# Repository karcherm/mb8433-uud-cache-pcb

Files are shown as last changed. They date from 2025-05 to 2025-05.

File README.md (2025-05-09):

1MB cache module for the Biostar MB-8433-UUD mainboard
======================================================

This adapter PCB enables you to install cache using SOJ32 chips, which are still in production. Furthermore,
with a modification of the mainboard, you can install up to 1MB of cache. To support 1MB of cache, you need
to grab A19 from the CPU and route it to the square header pin at the corner of this PCB.

Assembly hints
=========
For U1 to U8 (data RAM): Use 128k x 8 SRAM chips - the layout is not meant for 32k x 8 chips:
Neither does the address line ordering omit the "correct" lines if you install 32k x 8 chips,
nor is there sufficient bypassing at the Vcc pin for SOJ28 chips.

U9 can be a 128k x 8 or 64k x 8 SRAM chip. In case you just need 512K of cache, you can downgrade
U9 to 32k x 8. Sufficient bypassing for a 32k x 8 chip is present at this location. You can *not* downgrade
the data RAM to 64k x 8, though, as the address routing in version 1.1 is not adapted to this scenario.

Make sure to use sufficiently thin pins for plugging into the cache sockets.

Pay attention to the orientation of the memory chips: Pin 1 is always to the edge of the PCB, i.e.
U1-U4 are oriented the other way as U5-U9.

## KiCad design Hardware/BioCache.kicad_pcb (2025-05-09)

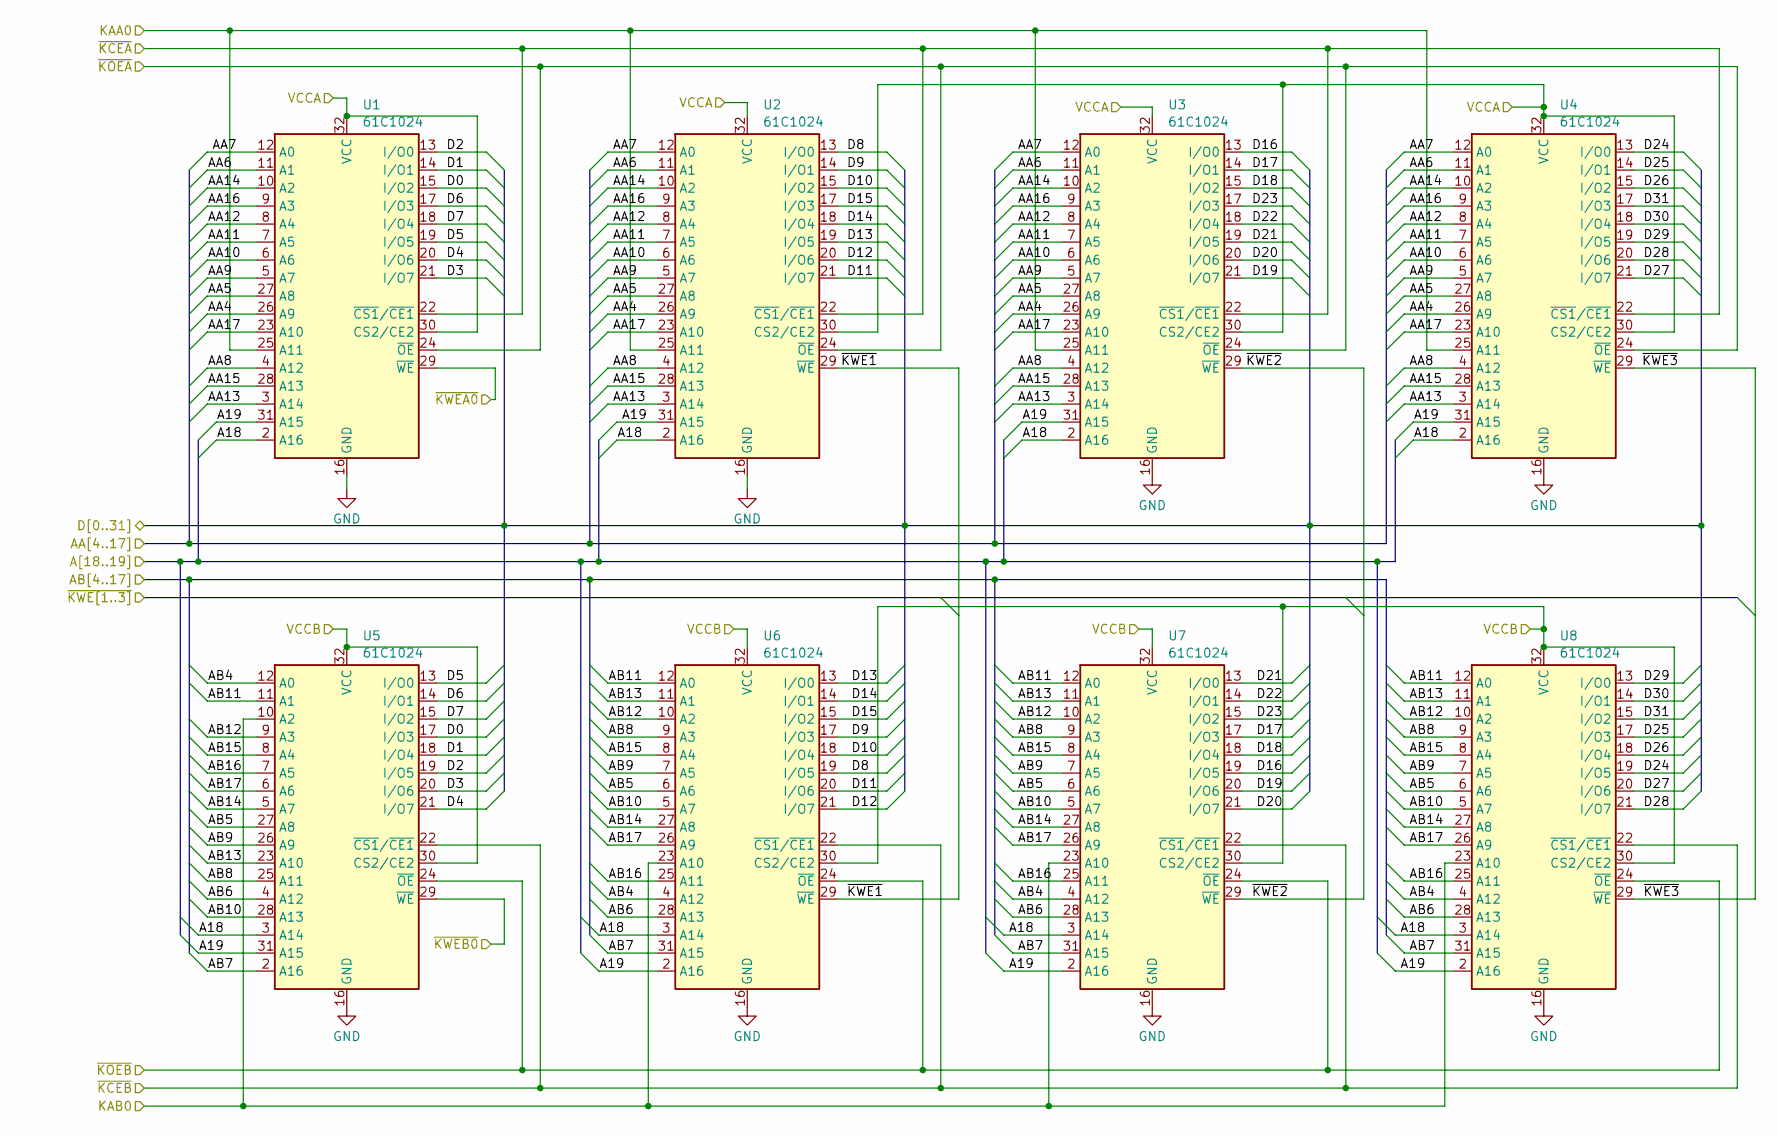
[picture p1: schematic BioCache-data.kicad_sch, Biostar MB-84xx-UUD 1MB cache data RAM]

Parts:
U1, U2, U3, U4, U5, U6, U7, U8: 61C1024; SOJ-32_7.62x20.955mm_P1.27mm

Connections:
/Data RAM/A18: U1.2 (A16), U2.2 (A16), U3.2 (A16), U4.2 (A16), U5.3 (A14), U6.3 (A14), U7.3 (A14), U8.3 (A14); also elsewhere on the board
/Data RAM/A19: U1.31 (A15), U2.31 (A15), U3.31 (A15), U4.31 (A15), U5.31 (A15), U6.2 (A16), U7.2 (A16), U8.2 (A16); also elsewhere on the board
/Data RAM/AA4: U1.26 (A9), U2.26 (A9), U3.26 (A9), U4.26 (A9); also elsewhere on the board
/Data RAM/AA5: U1.27 (A8), U2.27 (A8), U3.27 (A8), U4.27 (A8); also elsewhere on the board
/Data RAM/AA6: U1.11 (A1), U2.11 (A1), U3.11 (A1), U4.11 (A1); also elsewhere on the board
/Data RAM/AA7: U1.12 (A0), U2.12 (A0), U3.12 (A0), U4.12 (A0); also elsewhere on the board
/Data RAM/AA8: U1.4 (A12), U2.4 (A12), U3.4 (A12), U4.4 (A12); also elsewhere on the board
/Data RAM/AA9: U1.5 (A7), U2.5 (A7), U3.5 (A7), U4.5 (A7); also elsewhere on the board
/Data RAM/AA10: U1.6 (A6), U2.6 (A6), U3.6 (A6), U4.6 (A6); also elsewhere on the board
/Data RAM/AA11: U1.7 (A5), U2.7 (A5), U3.7 (A5), U4.7 (A5); also elsewhere on the board
/Data RAM/AA12: U1.8 (A4), U2.8 (A4), U3.8 (A4), U4.8 (A4); also elsewhere on the board
/Data RAM/AA13: U1.3 (A14), U2.3 (A14), U3.3 (A14), U4.3 (A14); also elsewhere on the board
/Data RAM/AA14: U1.10 (A2), U2.10 (A2), U3.10 (A2), U4.10 (A2); also elsewhere on the board
/Data RAM/AA15: U1.28 (A13), U2.28 (A13), U3.28 (A13), U4.28 (A13); also elsewhere on the board
/Data RAM/AA16: U1.9 (A3), U2.9 (A3), U3.9 (A3), U4.9 (A3); also elsewhere on the board
/Data RAM/AA17: U1.23 (A10), U2.23 (A10), U3.23 (A10), U4.23 (A10); also elsewhere on the board
/Data RAM/AB4: U5.12 (A0), U6.4 (A12), U7.4 (A12), U8.4 (A12); also elsewhere on the board
/Data RAM/AB5: U5.27 (A8), U6.6 (A6), U7.6 (A6), U8.6 (A6); also elsewhere on the board
/Data RAM/AB6: U5.4 (A12), U6.28 (A13), U7.28 (A13), U8.28 (A13); also elsewhere on the board
/Data RAM/AB7: U5.2 (A16), U6.31 (A15), U7.31 (A15), U8.31 (A15); also elsewhere on the board
/Data RAM/AB8: U5.25 (A11), U6.9 (A3), U7.9 (A3), U8.9 (A3); also elsewhere on the board
/Data RAM/AB9: U5.26 (A9), U6.7 (A5), U7.7 (A5), U8.7 (A5); also elsewhere on the board
/Data RAM/AB10: U5.28 (A13), U6.5 (A7), U7.5 (A7), U8.5 (A7); also elsewhere on the board
/Data RAM/AB11: U5.11 (A1), U6.12 (A0), U7.12 (A0), U8.12 (A0); also elsewhere on the board
/Data RAM/AB12: U5.9 (A3), U6.10 (A2), U7.10 (A2), U8.10 (A2); also elsewhere on the board
/Data RAM/AB13: U5.23 (A10), U6.11 (A1), U7.11 (A1), U8.11 (A1); also elsewhere on the board
/Data RAM/AB14: U5.5 (A7), U6.27 (A8), U7.27 (A8), U8.27 (A8); also elsewhere on the board
/Data RAM/AB15: U5.8 (A4), U6.8 (A4), U7.8 (A4), U8.8 (A4); also elsewhere on the board
/Data RAM/AB16: U5.7 (A5), U6.25 (A11), U7.25 (A11), U8.25 (A11); also elsewhere on the board
/Data RAM/AB17: U5.6 (A6), U6.26 (A9), U7.26 (A9), U8.26 (A9); also elsewhere on the board
/Data RAM/D0: U1.15 (I/O2), U5.17 (I/O3); also elsewhere on the board
/Data RAM/D1: U1.14 (I/O1), U5.18 (I/O4); also elsewhere on the board
/Data RAM/D2: U1.13 (I/O0), U5.19 (I/O5); also elsewhere on the board
/Data RAM/D3: U1.21 (I/O7), U5.20 (I/O6); also elsewhere on the board
/Data RAM/D4: U1.20 (I/O6), U5.21 (I/O7); also elsewhere on the board
/Data RAM/D5: U1.19 (I/O5), U5.13 (I/O0); also elsewhere on the board
/Data RAM/D6: U1.17 (I/O3), U5.14 (I/O1); also elsewhere on the board
/Data RAM/D7: U1.18 (I/O4), U5.15 (I/O2); also elsewhere on the board
/Data RAM/D8: U2.13 (I/O0), U6.19 (I/O5); also elsewhere on the board
/Data RAM/D9: U2.14 (I/O1), U6.17 (I/O3); also elsewhere on the board
/Data RAM/D10: U2.15 (I/O2), U6.18 (I/O4); also elsewhere on the board
/Data RAM/D11: U2.21 (I/O7), U6.20 (I/O6); also elsewhere on the board
/Data RAM/D12: U2.20 (I/O6), U6.21 (I/O7); also elsewhere on the board
/Data RAM/D13: U2.19 (I/O5), U6.13 (I/O0); also elsewhere on the board
/Data RAM/D14: U2.18 (I/O4), U6.14 (I/O1); also elsewhere on the board
/Data RAM/D15: U2.17 (I/O3), U6.15 (I/O2); also elsewhere on the board
/Data RAM/D16: U3.13 (I/O0), U7.19 (I/O5); also elsewhere on the board
/Data RAM/D17: U3.14 (I/O1), U7.17 (I/O3); also elsewhere on the board
/Data RAM/D18: U3.15 (I/O2), U7.18 (I/O4); also elsewhere on the board
/Data RAM/D19: U3.21 (I/O7), U7.20 (I/O6); also elsewhere on the board
/Data RAM/D20: U3.20 (I/O6), U7.21 (I/O7); also elsewhere on the board
/Data RAM/D21: U3.19 (I/O5), U7.13 (I/O0); also elsewhere on the board
/Data RAM/D22: U3.18 (I/O4), U7.14 (I/O1); also elsewhere on the board
/Data RAM/D23: U3.17 (I/O3), U7.15 (I/O2); also elsewhere on the board
/Data RAM/D24: U4.13 (I/O0), U8.19 (I/O5); also elsewhere on the board
/Data RAM/D25: U4.14 (I/O1), U8.17 (I/O3); also elsewhere on the board
/Data RAM/D26: U4.15 (I/O2), U8.18 (I/O4); also elsewhere on the board
/Data RAM/D27: U4.21 (I/O7), U8.20 (I/O6); also elsewhere on the board
/Data RAM/D28: U4.20 (I/O6), U8.21 (I/O7); also elsewhere on the board
/Data RAM/D29: U4.19 (I/O5), U8.13 (I/O0); also elsewhere on the board
/Data RAM/D30: U4.18 (I/O4), U8.14 (I/O1); also elsewhere on the board
/Data RAM/D31: U4.17 (I/O3), U8.15 (I/O2); also elsewhere on the board
/Data RAM/KAA0: U1.25 (A11), U2.25 (A11), U3.25 (A11), U4.25 (A11); also elsewhere on the board
/Data RAM/KAB0: U5.10 (A2), U6.23 (A10), U7.23 (A10), U8.23 (A10); also elsewhere on the board
/Data RAM/~KCEA: U1.22 (~CS1/~CE1), U2.22 (~CS1/~CE1), U3.22 (~CS1/~CE1), U4.22 (~CS1/~CE1); also elsewhere on the board
/Data RAM/~KCEB: U5.22 (~CS1/~CE1), U6.22 (~CS1/~CE1), U7.22 (~CS1/~CE1), U8.22 (~CS1/~CE1); also elsewhere on the board
/Data RAM/~KOEA: U1.24 (~OE), U2.24 (~OE), U3.24 (~OE), U4.24 (~OE); also elsewhere on the board
/Data RAM/~KOEB: U5.24 (~OE), U6.24 (~OE), U7.24 (~OE), U8.24 (~OE); also elsewhere on the board
/Data RAM/~KWE1: U2.29 (~WE), U6.29 (~WE); also elsewhere on the board
/Data RAM/~KWE2: U3.29 (~WE), U7.29 (~WE); also elsewhere on the board
/Data RAM/~KWE3: U4.29 (~WE), U8.29 (~WE); also elsewhere on the board
/Data RAM/~KWEA0: U1.29 (~WE); also elsewhere on the board
/Data RAM/~KWEB0: U5.29 (~WE); also elsewhere on the board
/Tag RAM and Connectors/VCCA: U1.30 (CS2/CE2), U1.32 (VCC), U2.30 (CS2/CE2), U2.32 (VCC), U3.30 (CS2/CE2), U3.32 (VCC), U4.30 (CS2/CE2), U4.32 (VCC); also elsewhere on the board
/Tag RAM and Connectors/VCCB: U5.30 (CS2/CE2), U5.32 (VCC), U6.30 (CS2/CE2), U6.32 (VCC), U7.30 (CS2/CE2), U7.32 (VCC), U8.30 (CS2/CE2), U8.32 (VCC); also elsewhere on the board
GND: U1.16 (GND), U2.16 (GND), U3.16 (GND), U4.16 (GND), U5.16 (GND), U6.16 (GND), U7.16 (GND), U8.16 (GND); also elsewhere on the board

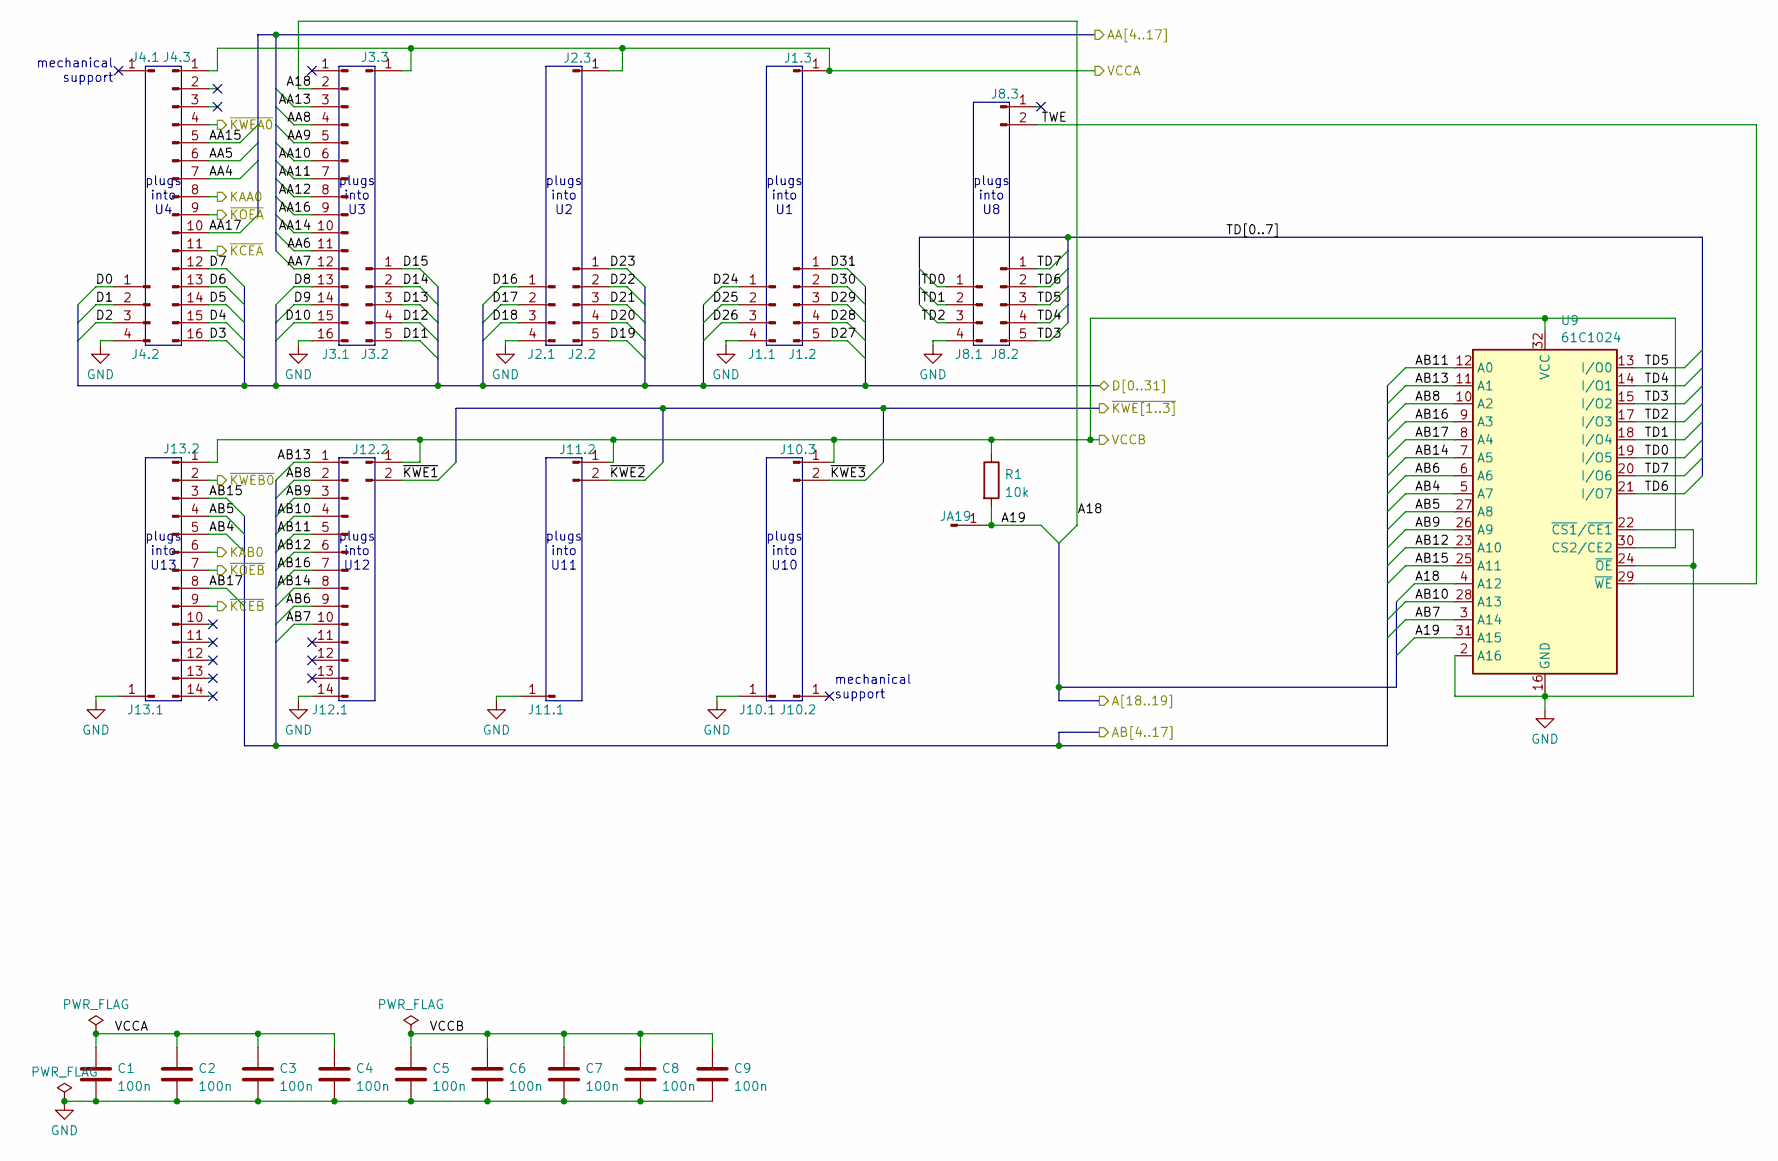
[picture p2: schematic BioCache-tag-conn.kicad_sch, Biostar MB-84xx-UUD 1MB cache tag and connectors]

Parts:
C1, C2, C3, C4, C5, C6, C7, C8, C9: 100n; C_0805_2012Metric_Pad1.18x1.45mm_HandSolder
J1.1, J2.1, J4.2, J8.1: Conn_01x04_Male; PinHeader_1x04_P2.54mm_Vertical_NoSquare1
J1.2, J2.2, J3.2, J8.2: Conn_01x05_Male; PinHeader_1x05_P2.54mm_Vertical_NoSquare1
J1.3, J2.3, J3.3, J4.1, J10.1, J10.2, J11.1, J13.1: Conn_01x01_Male; PinHeader_1x01_P2.54mm_Vertical_NoSquare1
J3.1, J4.3: Conn_01x16_Male; PinHeader_1x16_P2.54mm_Vertical_NoSquare1
J8.3, J10.3, J11.2, J12.2: Conn_01x02_Male; PinHeader_1x02_P2.54mm_Vertical_NoSquare1
J12.1, J13.2: Conn_01x14_Male; PinHeader_1x14_P2.54mm_Vertical_NoSquare1
JA19: Conn_01x01_Male; PinHeader_1x01_P2.54mm_Horizontal
R1: 10k; R_0805_2012Metric_Pad1.20x1.40mm_HandSolder
U9: 61C1024; SOJ-32_7.62x20.955mm_P1.27mm

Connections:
/Data RAM/A18: J3.1.2, U9.4 (A12); also elsewhere on the board
/Data RAM/A19: JA19.1, R1.2, U9.31 (A15); also elsewhere on the board
/Data RAM/AA4: J4.3.7; also elsewhere on the board
/Data RAM/AA5: J4.3.6; also elsewhere on the board
/Data RAM/AA6: J3.1.11; also elsewhere on the board
/Data RAM/AA7: J3.1.12; also elsewhere on the board
/Data RAM/AA8: J3.1.4; also elsewhere on the board
/Data RAM/AA9: J3.1.5; also elsewhere on the board
/Data RAM/AA10: J3.1.6; also elsewhere on the board
/Data RAM/AA11: J3.1.7; also elsewhere on the board
/Data RAM/AA12: J3.1.8; also elsewhere on the board
/Data RAM/AA13: J3.1.3; also elsewhere on the board
/Data RAM/AA14: J3.1.10; also elsewhere on the board
/Data RAM/AA15: J4.3.5; also elsewhere on the board
/Data RAM/AA16: J3.1.9; also elsewhere on the board
/Data RAM/AA17: J4.3.10; also elsewhere on the board
/Data RAM/AB4: J13.2.5, U9.5 (A7); also elsewhere on the board
/Data RAM/AB5: J13.2.4, U9.27 (A8); also elsewhere on the board
/Data RAM/AB6: J12.1.9, U9.6 (A6); also elsewhere on the board
/Data RAM/AB7: J12.1.10, U9.3 (A14); also elsewhere on the board
/Data RAM/AB8: J12.1.2, U9.10 (A2); also elsewhere on the board
/Data RAM/AB9: J12.1.3, U9.26 (A9); also elsewhere on the board
/Data RAM/AB10: J12.1.4, U9.28 (A13); also elsewhere on the board
/Data RAM/AB11: J12.1.5, U9.12 (A0); also elsewhere on the board
/Data RAM/AB12: J12.1.6, U9.23 (A10); also elsewhere on the board
/Data RAM/AB13: J12.1.1, U9.11 (A1); also elsewhere on the board
/Data RAM/AB14: J12.1.8, U9.7 (A5); also elsewhere on the board
/Data RAM/AB15: J13.2.3, U9.25 (A11); also elsewhere on the board
/Data RAM/AB16: J12.1.7, U9.9 (A3); also elsewhere on the board
/Data RAM/AB17: J13.2.8, U9.8 (A4); also elsewhere on the board
/Data RAM/D0: J4.2.1; also elsewhere on the board
/Data RAM/D1: J4.2.2; also elsewhere on the board
/Data RAM/D2: J4.2.3; also elsewhere on the board
/Data RAM/D3: J4.3.16; also elsewhere on the board
/Data RAM/D4: J4.3.15; also elsewhere on the board
/Data RAM/D5: J4.3.14; also elsewhere on the board
/Data RAM/D6: J4.3.13; also elsewhere on the board
/Data RAM/D7: J4.3.12; also elsewhere on the board
/Data RAM/D8: J3.1.13; also elsewhere on the board
/Data RAM/D9: J3.1.14; also elsewhere on the board
/Data RAM/D10: J3.1.15; also elsewhere on the board
/Data RAM/D11: J3.2.5; also elsewhere on the board
/Data RAM/D12: J3.2.4; also elsewhere on the board
/Data RAM/D13: J3.2.3; also elsewhere on the board
/Data RAM/D14: J3.2.2; also elsewhere on the board
/Data RAM/D15: J3.2.1; also elsewhere on the board
/Data RAM/D16: J2.1.1; also elsewhere on the board
/Data RAM/D17: J2.1.2; also elsewhere on the board
/Data RAM/D18: J2.1.3; also elsewhere on the board
/Data RAM/D19: J2.2.5; also elsewhere on the board
/Data RAM/D20: J2.2.4; also elsewhere on the board
/Data RAM/D21: J2.2.3; also elsewhere on the board
/Data RAM/D22: J2.2.2; also elsewhere on the board
/Data RAM/D23: J2.2.1; also elsewhere on the board
/Data RAM/D24: J1.1.1; also elsewhere on the board
/Data RAM/D25: J1.1.2; also elsewhere on the board
/Data RAM/D26: J1.1.3; also elsewhere on the board
/Data RAM/D27: J1.2.5; also elsewhere on the board
/Data RAM/D28: J1.2.4; also elsewhere on the board
/Data RAM/D29: J1.2.3; also elsewhere on the board
/Data RAM/D30: J1.2.2; also elsewhere on the board
/Data RAM/D31: J1.2.1; also elsewhere on the board
/Data RAM/KAA0: J4.3.8; also elsewhere on the board
/Data RAM/KAB0: J13.2.6; also elsewhere on the board
/Data RAM/~KCEA: J4.3.11; also elsewhere on the board
/Data RAM/~KCEB: J13.2.9; also elsewhere on the board
/Data RAM/~KOEA: J4.3.9; also elsewhere on the board
/Data RAM/~KOEB: J13.2.7; also elsewhere on the board
/Data RAM/~KWE1: J12.2.2; also elsewhere on the board
/Data RAM/~KWE2: J11.2.2; also elsewhere on the board
/Data RAM/~KWE3: J10.3.2; also elsewhere on the board
/Data RAM/~KWEA0: J4.3.4; also elsewhere on the board
/Data RAM/~KWEB0: J13.2.2; also elsewhere on the board
/Tag RAM and Connectors/TD0: J8.1.1, U9.19 (I/O5)
/Tag RAM and Connectors/TD1: J8.1.2, U9.18 (I/O4)
/Tag RAM and Connectors/TD2: J8.1.3, U9.17 (I/O3)
/Tag RAM and Connectors/TD3: J8.2.5, U9.15 (I/O2)
/Tag RAM and Connectors/TD4: J8.2.4, U9.14 (I/O1)
/Tag RAM and Connectors/TD5: J8.2.3, U9.13 (I/O0)
/Tag RAM and Connectors/TD6: J8.2.2, U9.21 (I/O7)
/Tag RAM and Connectors/TD7: J8.2.1, U9.20 (I/O6)
/Tag RAM and Connectors/TWE: J8.3.2, U9.29 (~WE)
/Tag RAM and Connectors/VCCA: C1.1, C2.1, C3.1, C4.1, J1.3.1, J2.3.1, J3.3.1, J4.3.1; also elsewhere on the board
/Tag RAM and Connectors/VCCB: C5.1, C6.1, C7.1, C8.1, C9.1, J10.3.1, J11.2.1, J12.2.1, J13.2.1, R1.1, U9.30 (CS2/CE2), U9.32 (VCC); also elsewhere on the board
GND: C1.2, C2.2, C3.2, C4.2, C5.2, C6.2, C7.2, C8.2, C9.2, J1.1.4, J2.1.4, J3.1.16, J4.2.4, J8.1.4, J10.1.1, J11.1.1, J12.1.14, J13.1.1, U9.2 (A16), U9.16 (GND), U9.22 (~CS1/~CE1), U9.24 (~OE); also elsewhere on the board

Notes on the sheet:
plugs into U11
plugs into U4
mechanical support
plugs into U12
plugs into U2
plugs into U10
plugs into U1
plugs into U8
plugs into U3
plugs into U13

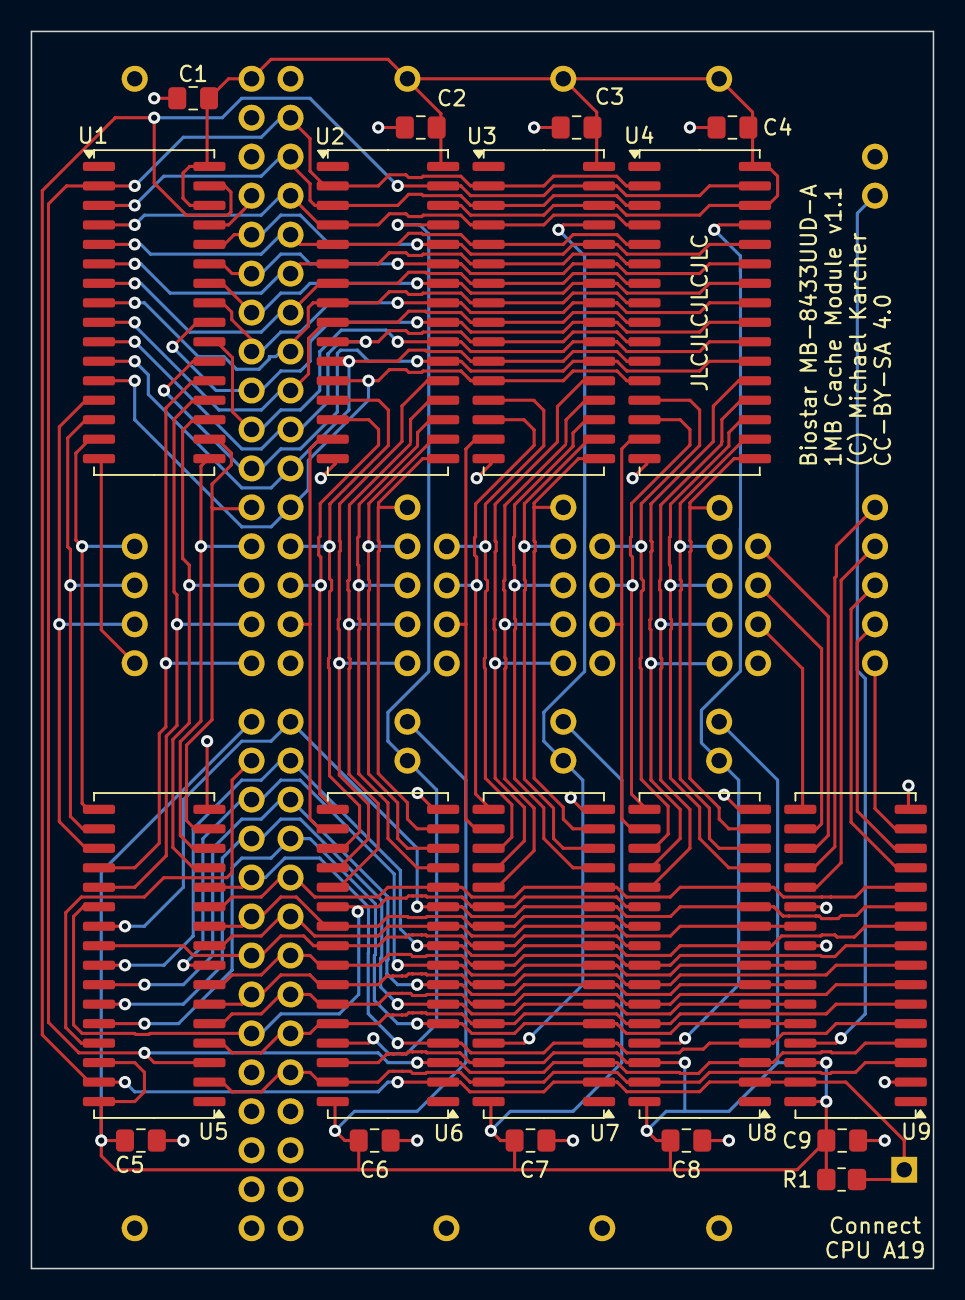
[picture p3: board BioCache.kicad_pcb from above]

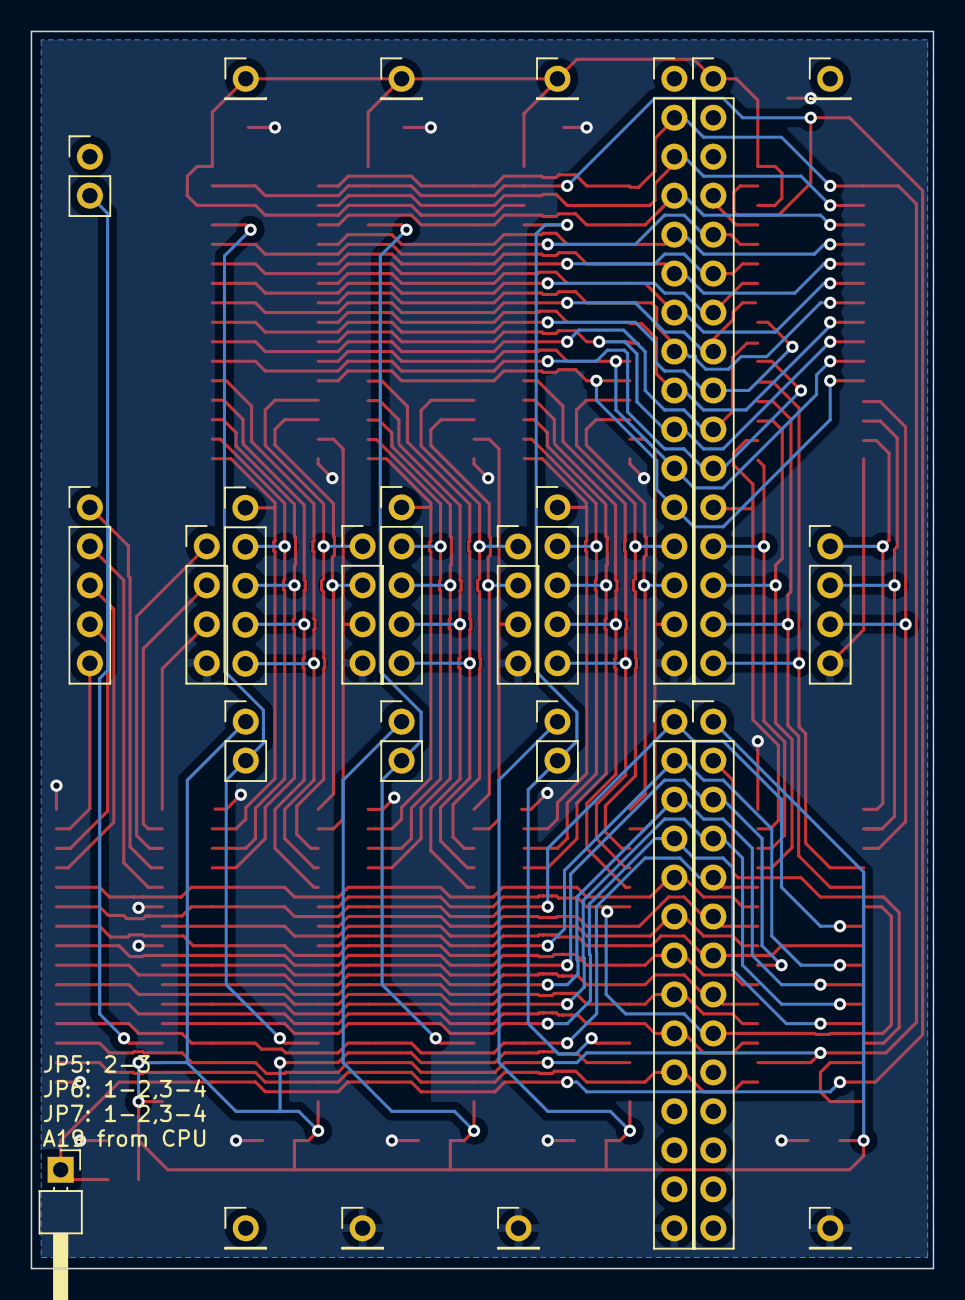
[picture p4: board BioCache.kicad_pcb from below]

Board: 2 copper layers, 58.8 x 80.6 mm, 44 parts (25 on the bottom side), 85 nets.

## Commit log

2023-08-05 Initial checkin of the hardware design
    [BioCache-data.kicad_sch, BioCache-tag-conn.kicad_sch, BioCache.kicad_pcb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]
2023-08-05 Update PCB from library
    [BioCache.kicad_pcb]
2025-05-04 Upgrade to KiCad 9, clean-up schematics, set up KiBot
    [BioCache-data.kicad_sch, BioCache-tag-conn.kicad_sch, BioCache.kicad_pcb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]
2025-05-04 build KiCad stuff for releases
2025-05-09 Re-Route U9 (TAG ram) to support 32K*8 and 64K*8
    [BioCache-tag-conn.kicad_sch, BioCache.kicad_sch]
2025-05-09 Ûpdate SOJ32 footprints to wider layout
    Reroute traces as required.
    [BioCache.kicad_pcb]
2025-05-09 Remove custom definition of SOJ32 memory chip
    [BioCache-data.kicad_sch, BioCache-tag-conn.kicad_sch, BioCache.kicad_pcb]
2025-05-09 Update modification date
    [BioCache-data.kicad_sch, BioCache-tag-conn.kicad_sch, BioCache.kicad_pcb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]

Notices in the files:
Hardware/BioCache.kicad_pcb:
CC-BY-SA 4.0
